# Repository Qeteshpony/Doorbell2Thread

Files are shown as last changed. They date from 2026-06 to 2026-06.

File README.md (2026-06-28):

# Doorbell2Thread

### Turning an old analog doorbell into a smart one... 



3D Render

[Hardware Documentation](https://qeteshpony.github.io/Doorbell2Thread)

# Hardware description

This is a very simple device that can be connected to an old analog intercom system to notify home assistant about someone ringing the bell. This was specifically made for the system in the house I live in but it might be compatible with yours as well - no guarantees though. 

I am using a small form factor ESP32-H2 module (Waveshare ESP32-H2 Mini) because the H2 is low power and the power supply for the intercom can't handle much current. 

There's also some protective circuitry since my first prototype got completely fried by induced voltages in the intercom cables. This version now runs stable and without problems. 

# Software

This is running on ESPHome. My configuration is available in this repo, see [doorbell.yaml](doorbell.yaml) (You of course have to add your secrets before using it...) 

This configuration is using the built in RGB led on the ESP-module to show the status. It's brightness can be tuned through Home Assistant to make it visible through the case if desired.

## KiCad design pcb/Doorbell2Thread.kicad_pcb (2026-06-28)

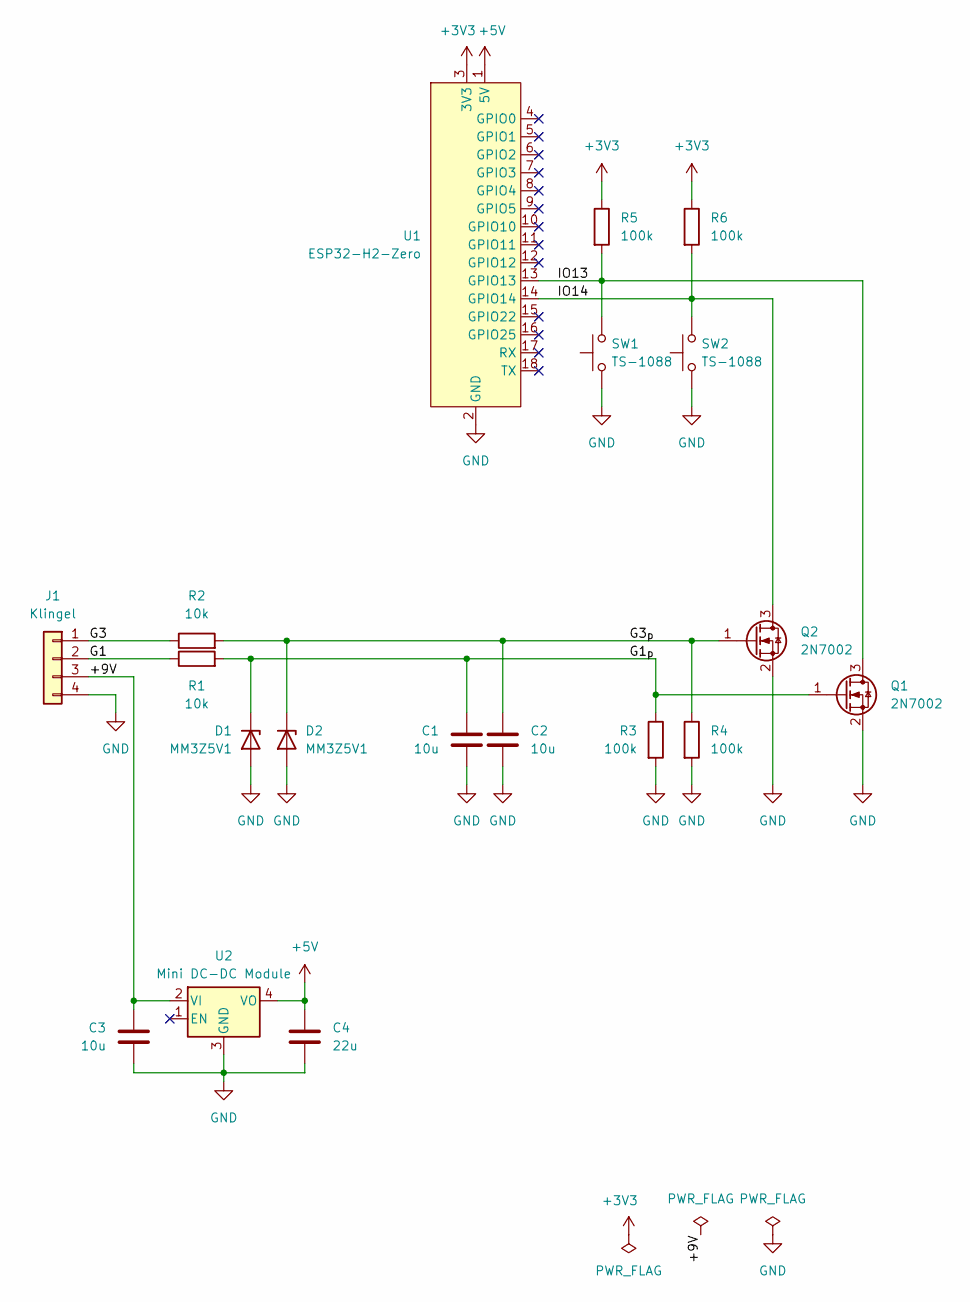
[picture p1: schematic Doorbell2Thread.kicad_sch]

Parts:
C1, C2: 10u; C_0603_1608Metric; LCSC C19702
C3: 10u; C_0805_2012Metric; LCSC C440198
C4: 22u; C_0805_2012Metric; LCSC C45783
D1, D2: MM3Z5V1; D_SOD-323; LCSC C19077455
J1: Klingel; JST_PH_S4B-PH-K_1x04_P2.00mm_Horizontal
Q1, Q2: 2N7002; SOT-23; LCSC C8545
R1, R2: 10k; R_0402_1005Metric; LCSC C25744
R3, R4, R5, R6: 100k; R_0402_1005Metric; LCSC C25741
SW1, SW2: TS-1088; SW_Push_SPST_NO_Alps_SKRK; LCSC C720477
U1: ESP32-H2-Zero
U2: Mini DC-DC Module

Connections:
+3V3: R5.1, R6.1, U1.3 (3V3)
+5V: C4.1, U1.1 (5V), U2.4 (VO)
/+9V: C3.1, J1.3, U2.2 (VI)
/G1: J1.2, R1.1
/G1_{p}: C1.1, D1.1 (K), Q1.1 (G), R1.2, R3.1
/G3: J1.1, R2.1
/G3_{p}: C2.1, D2.1 (K), Q2.1 (G), R2.2, R4.1
/IO13: Q1.3 (D), R5.2, SW1.2, U1.13 (GPIO13)
/IO14: Q2.3 (D), R6.2, SW2.2, U1.14 (GPIO14)
GND: C1.2, C2.2, C3.2, C4.2, D1.2 (A), D2.2 (A), J1.4, Q1.2 (S), Q2.2 (S), R3.2, R4.2, SW1.1, SW2.1, U1.2 (GND), U2.3 (GND)

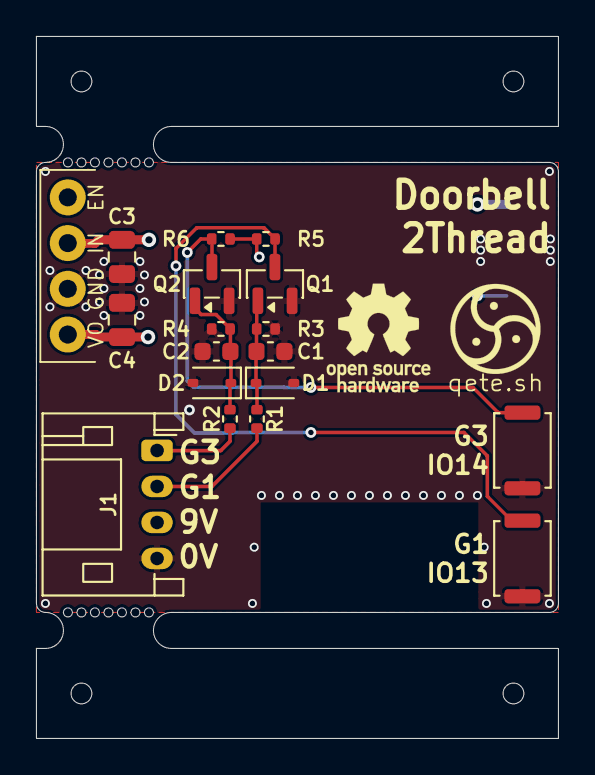
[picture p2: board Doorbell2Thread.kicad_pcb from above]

Board: 4 copper layers, 29.0 x 39.0 mm, 21 parts (1 on the bottom side), 10 nets.

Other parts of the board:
mouse-bite-2mm-slot, mouse-bite-2mm-slot#2: VAL**; mouse-bite-2x5mm-slot-onesided-v2

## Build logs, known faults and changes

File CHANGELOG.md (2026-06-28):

# Changelog

## 1.0.0 (2026-06-28)

### Features

* add yaml for ESPHome ([a8bd0f4](https://github.com/Qeteshpony/Doorbell2Thread/commit/a8bd0f438039cde669aae2f122734f56465c721f))
* initial commit ([a8ba936](https://github.com/Qeteshpony/Doorbell2Thread/commit/a8ba936e5ccd0fb3488365d10a38e3523a222e3e))
* replaced the expensive LME78 ([55fa685](https://github.com/Qeteshpony/Doorbell2Thread/commit/55fa685b75fbed76862face0f959210e2038e2f3))

### Bug Fixes

* add protection circuitry ([55fa685](https://github.com/Qeteshpony/Doorbell2Thread/commit/55fa685b75fbed76862face0f959210e2038e2f3))
* update to KiCad 10 ([55fa685](https://github.com/Qeteshpony/Doorbell2Thread/commit/55fa685b75fbed76862face0f959210e2038e2f3))

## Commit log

2025-12-07 feat: initial commit
    [Doorbell2Thread.kicad_pcb, Doorbell2Thread.kicad_sch]
2026-06-28 fix: add protection circuitry
    The doorbell was killing the mosfets on the board so some protection was needed
    feat: replaced the expensive LME78
    This caused a major redesign of the whole board
    fix: update to KiCad 10
    [Doorbell2Thread.kicad_pcb, Doorbell2Thread.kicad_sch]
